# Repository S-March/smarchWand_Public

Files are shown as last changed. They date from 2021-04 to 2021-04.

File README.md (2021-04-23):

# smarchWand

smarchWand

I'm a huge dork. I love magic, have since I was a little kid. Now that I'm a grown up with some technical background knowledge, I made my own REAL magic wand!

For future projects and progress pictures, follow me on instagram @SamsonMarch

## Other Useful Links
To order circuit boards from the same place I did (with all the files pre-loaded and tech parameters filled out), you can [click this link](https://www.pcbway.com/project/shareproject/smarchWand.html)

To download the SDK for the DA14531, you can [click this link](https://support.dialog-semiconductor.com/system/files/restricted/SDK_6.0.14.1114.zip)

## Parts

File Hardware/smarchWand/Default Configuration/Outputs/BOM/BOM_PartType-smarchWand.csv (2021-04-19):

Quantity | Designator | Comment | Description
5 | R2, R3, R4, R5, R6 | 10k | 0402 Resistor
3 | C1, C3, C7 | 10uF | 0402 Capacitor
3 | C2, C5, C6 | 4.7uF | 0402 Capacitor
2 | R9, R10 | 5.1M | 0402 Resistor
1 | ANT1 | 2450AT18D0100E | 2450AT18D0100E 2.4GHz Chip RF Antenna 2.4GHz ~ 2.5GHz 1.5dBi Solder Surface Mount
1 | C4 | 100nF | 0402 Capacitor
1 | C8 | 1uF | 0402 Capacitor
1 | D1 | CUS10S30,H3F | CUS10S30,H3F Diode Schottky 30V 1A Surface Mount USC
1 | D2 | D5V0L1B2LP4-7B | D5V0L1B2LP4-7B 14V Clamp 6A (8/20µs) Ipp Tvs Diode Surface Mount X2-DFN1006-2
1 | L1 | CIGT201610EH2R2MNE | CIGT201610EH2R2MNE 2.2µH Unshielded Thin Film Inductor 2.5A 87mOhm Max 0806 (2016 Metric)
1 | M1 | C0720B001F | C0720B001F DC Motor Vibration, ERM 10000 RPM 3VDC
1 | P1 | TC2030-CTX-NL | TC2030-CTX-NL Tag Connect Cable
1 | Q1 | 2N7002K-7 | 2N7002K-7 MOSFET N-CH 60V 380MA SOT23-3
1 | Q2 | BSS84AKM,315 | BSS84AKM,315 MOSFET P-CH 50V SOT883
1 | Q3 | ECH8693R | Mosfet Array 2 N-Channel (Dual) Common Drain 24V 14A 1.4W Surface Mount SOT-28FL/ECH8
1 | R1 | 100 | 0805 Resistor
1 | R11 | 6.8k | 0402 Resistor
1 | R7 | 330 | 0402 Resistor
1 | R8 | 2.2K | 0402 Resistor
1 | U1 | DA14531 | DA14531 IC RF TxRx + MCU Bluetooth Bluetooth v5.1 2.4GHz 24-WFQFN, FC
1 | U2 | W25X20CLUXIG | W25X20CLUXIG FLASH Memory IC 2Mb (256K x 8) SPI 104MHz 8-USON (2x3)
1 | U3 | BQ29700DSER | Battery Battery Protection IC Lithium-Ion/Polymer 6-WSON (1.5x1.5)
1 | U4 | LM3671 | LM3671 IC REG BUCK 3.3V 0.6A SYNC 5USMD
1 | U5 | MCP73831T-2ACI/MC | MCP73831T-2ACI/MC Charger IC Lithium-Ion/Polymer
1 | U6 | LIS3DH | LIS3DH ACCEL 2-16G I2C/SPI 16LGA
1 | X1 | ECS-320-8-37B-CKY | ECS-320-8-37B-CKY CRYSTAL 32.0000MHZ 8PF SMD

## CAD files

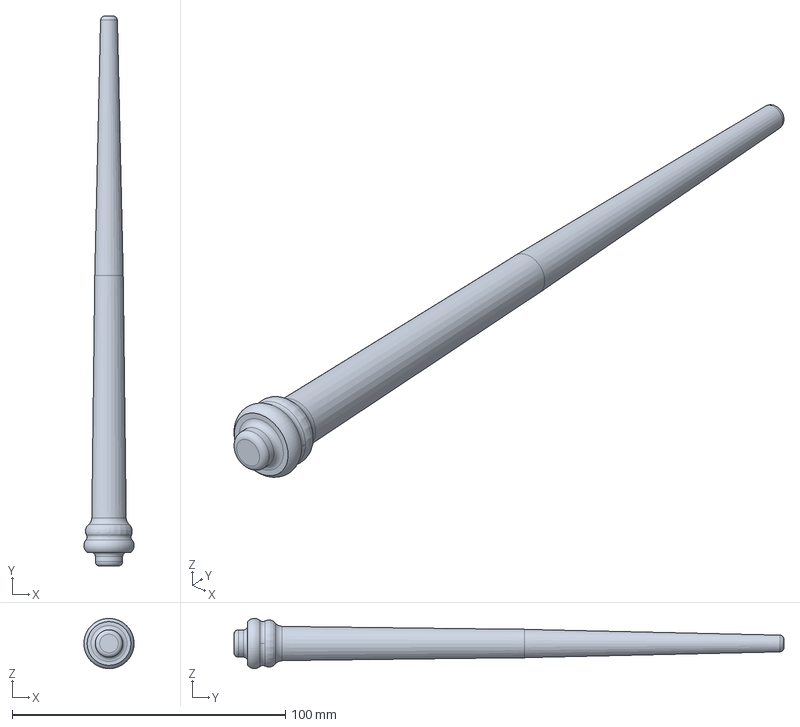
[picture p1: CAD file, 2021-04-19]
Housing/bodyShapeTopCap.step
18.4 x 201.4 x 18.4 mm

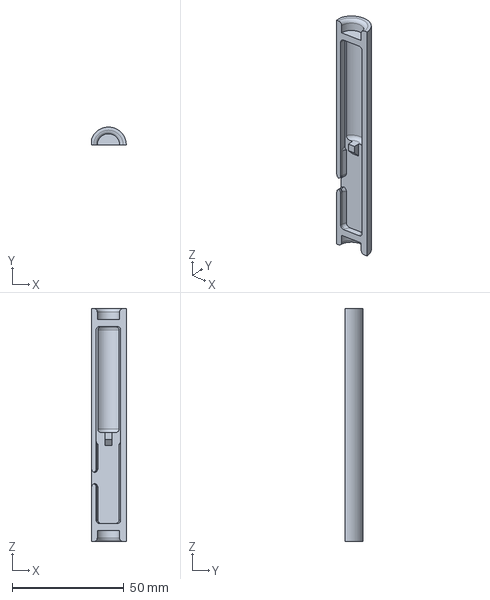
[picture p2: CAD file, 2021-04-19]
Housing/bodyShapeCenterTop.step
15.5 x 8.00 x 104.1 mm

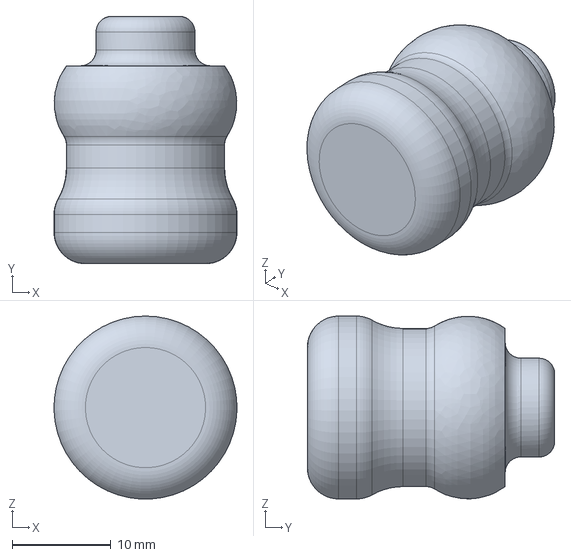
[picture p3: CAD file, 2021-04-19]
Housing/bodyShapeBottomCap.step
18.5 x 25.0 x 18.5 mm

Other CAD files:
Housing/bodyShapeCenterBottom.step

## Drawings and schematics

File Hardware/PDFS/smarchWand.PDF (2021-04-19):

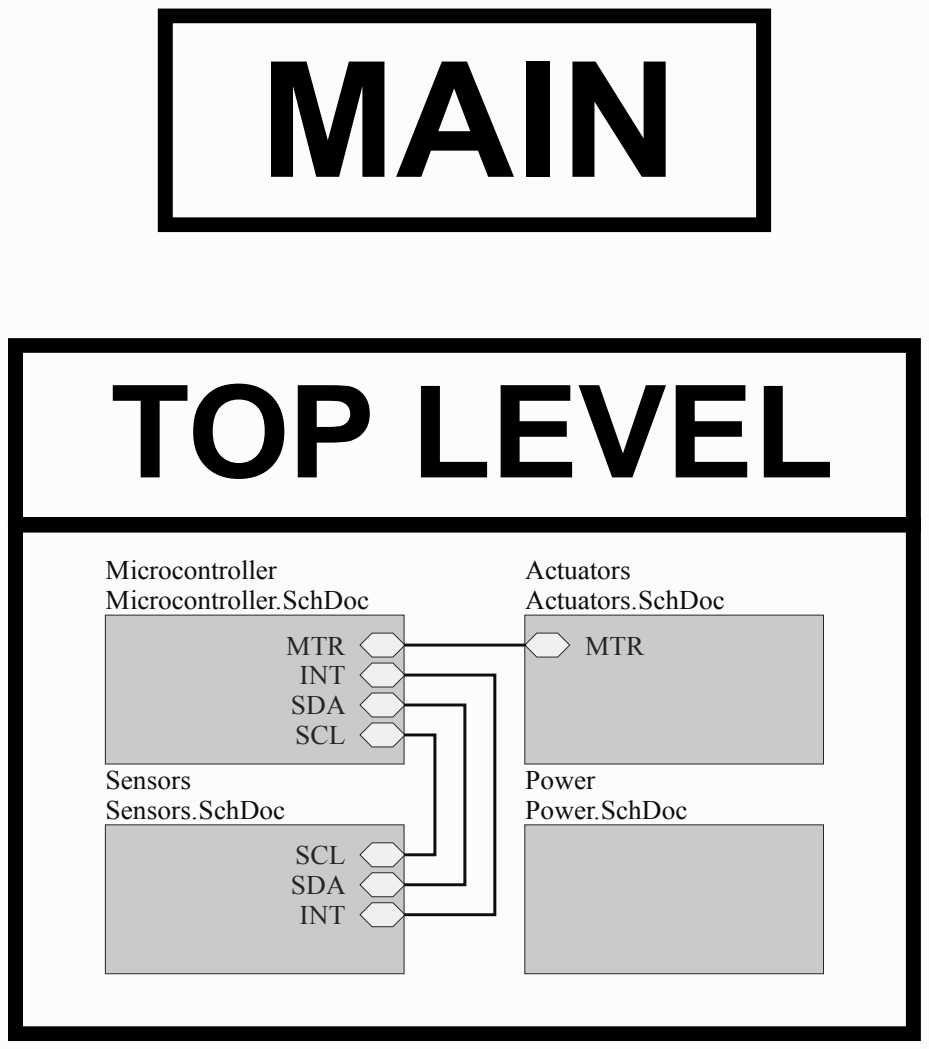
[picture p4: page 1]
TOP LEVEL

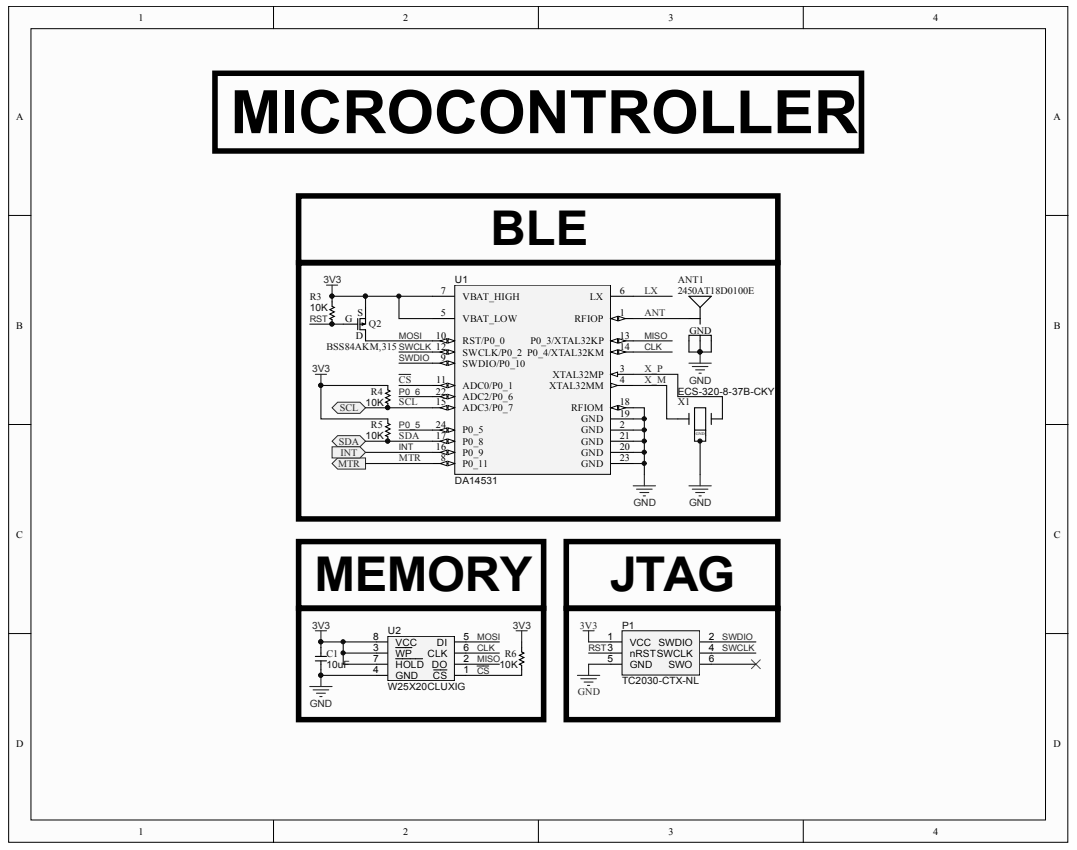
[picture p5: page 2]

R4 10K SCL | P0_6 | ADC3/P0_7 15 ADC2/P0_6 22 ADC0/P0_1 11

X_M GND

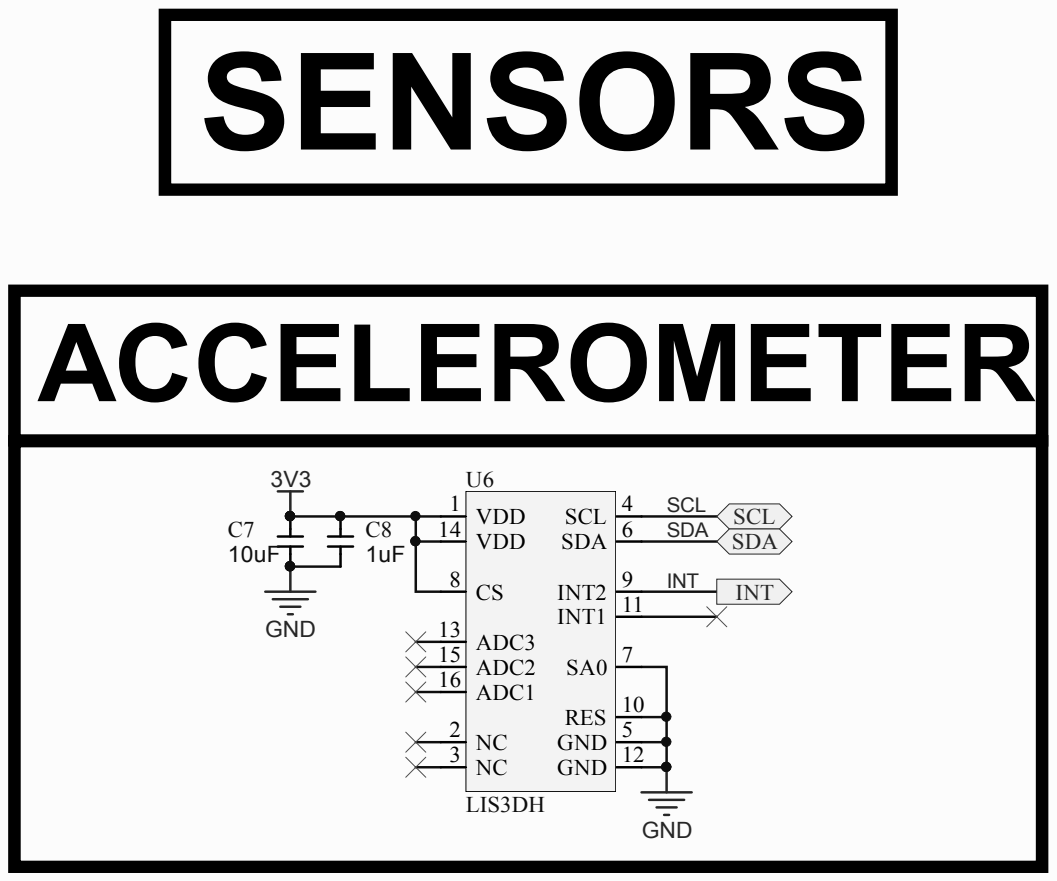
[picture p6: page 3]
VDD 1; INT2; ADC3 13; VDD 14; ADC2 15 ADC1 16

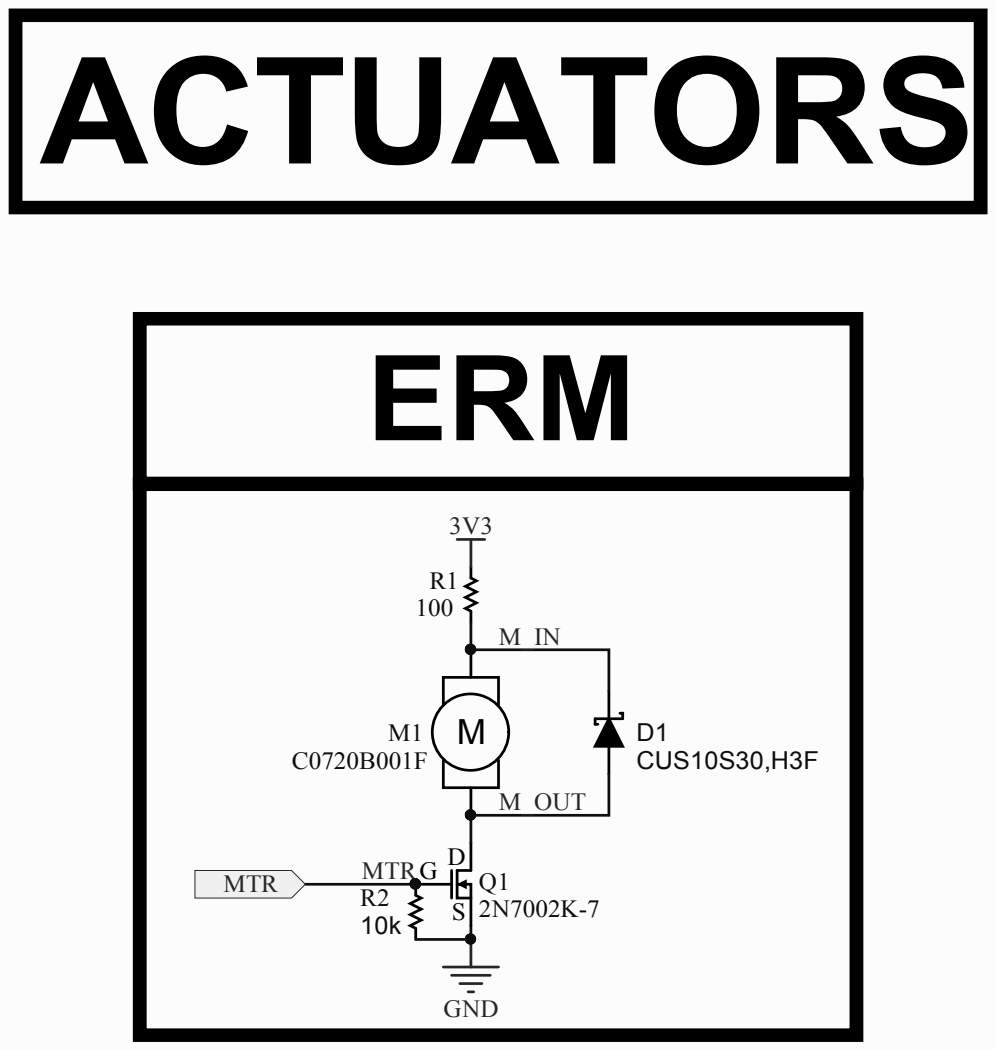
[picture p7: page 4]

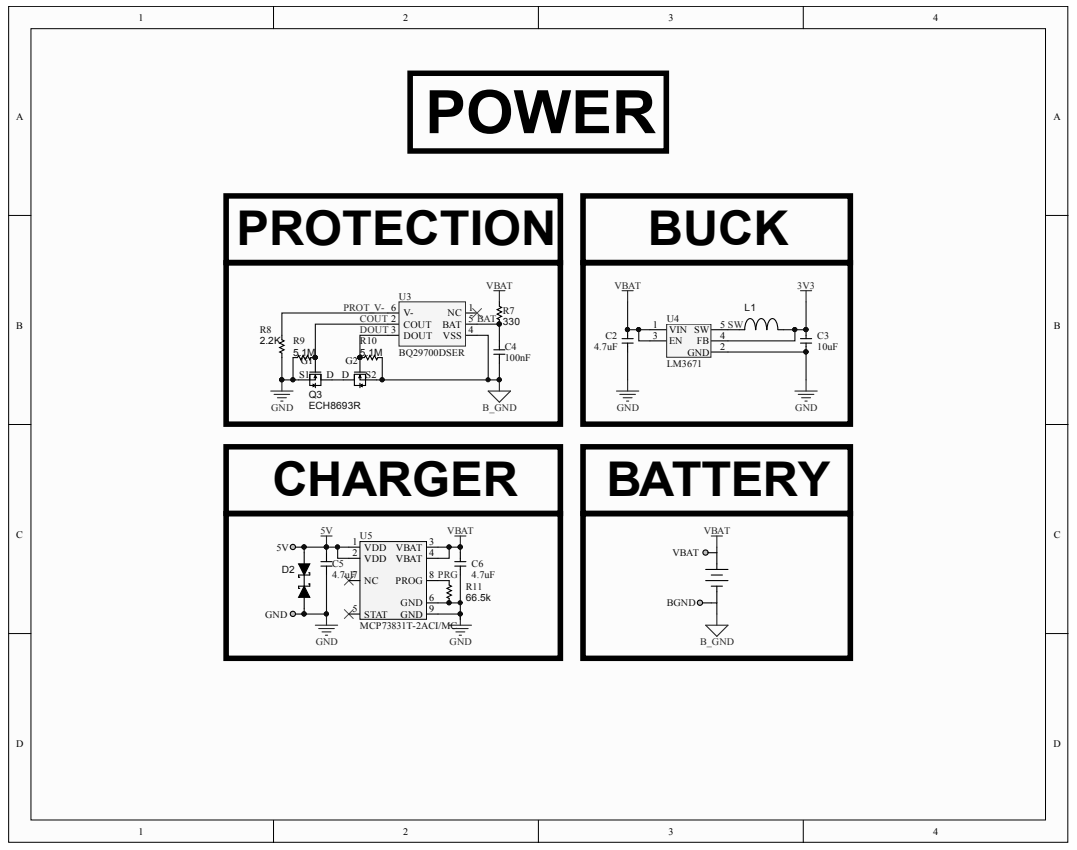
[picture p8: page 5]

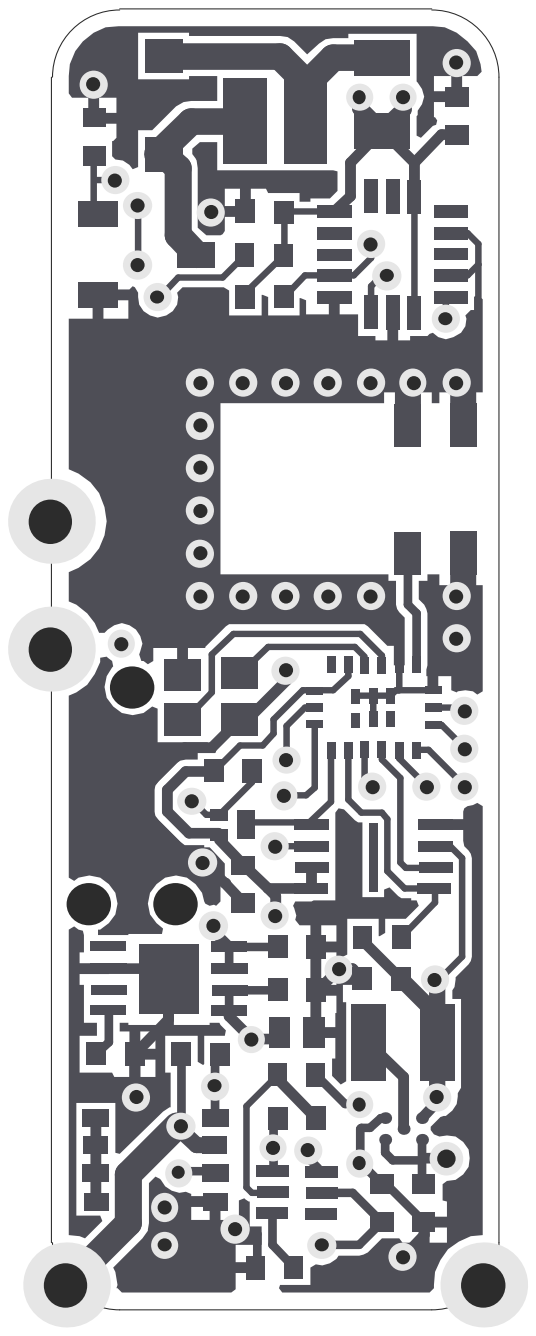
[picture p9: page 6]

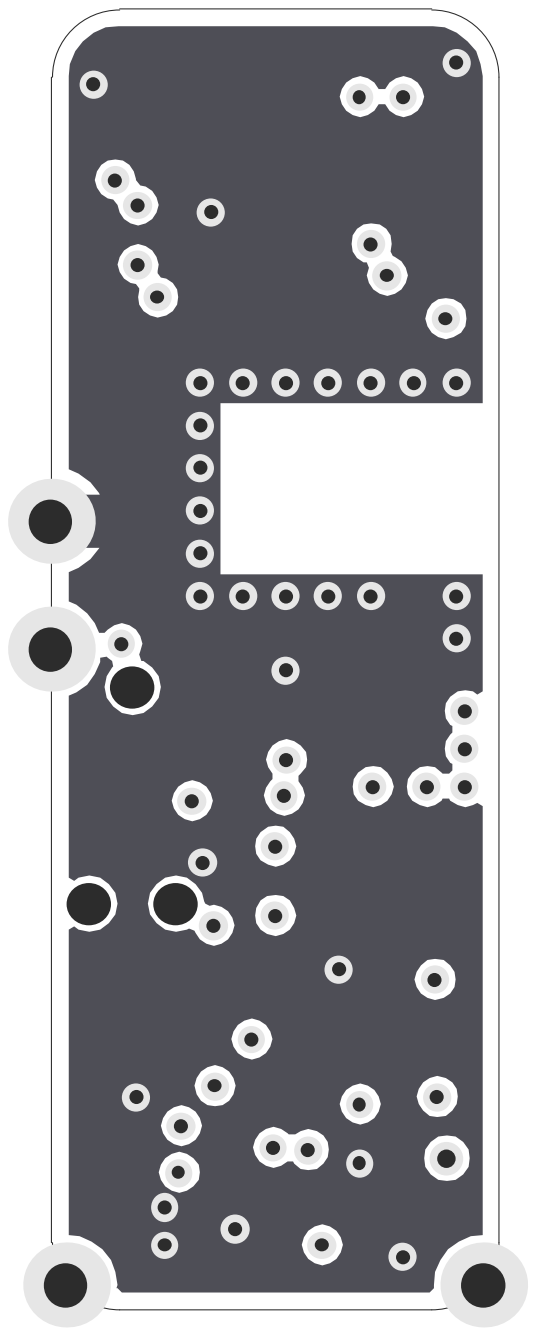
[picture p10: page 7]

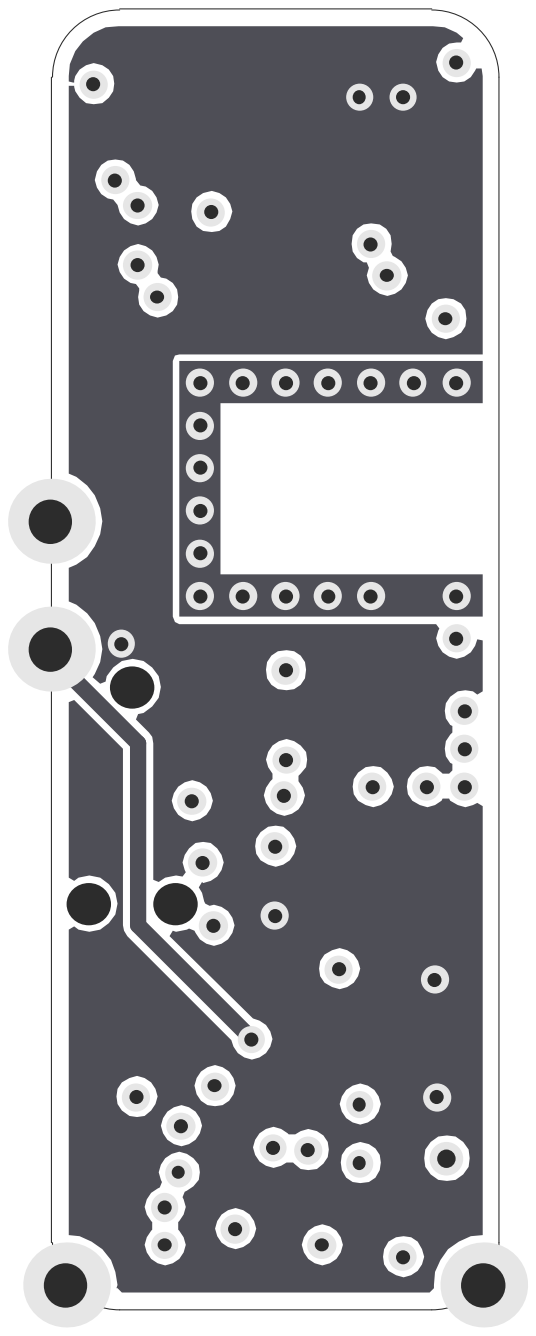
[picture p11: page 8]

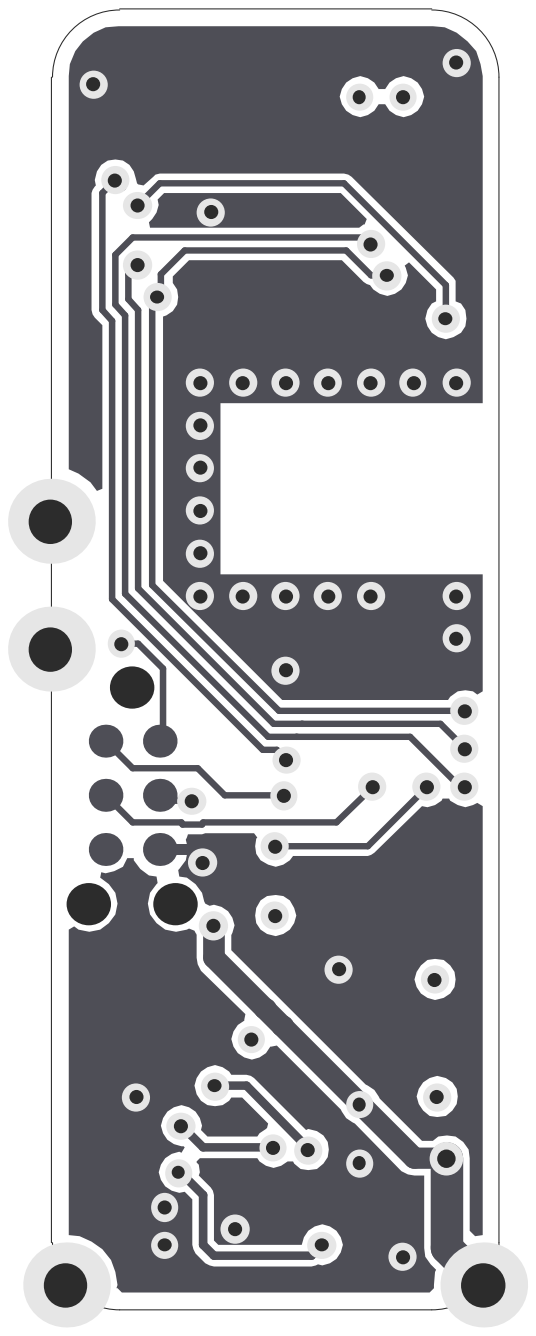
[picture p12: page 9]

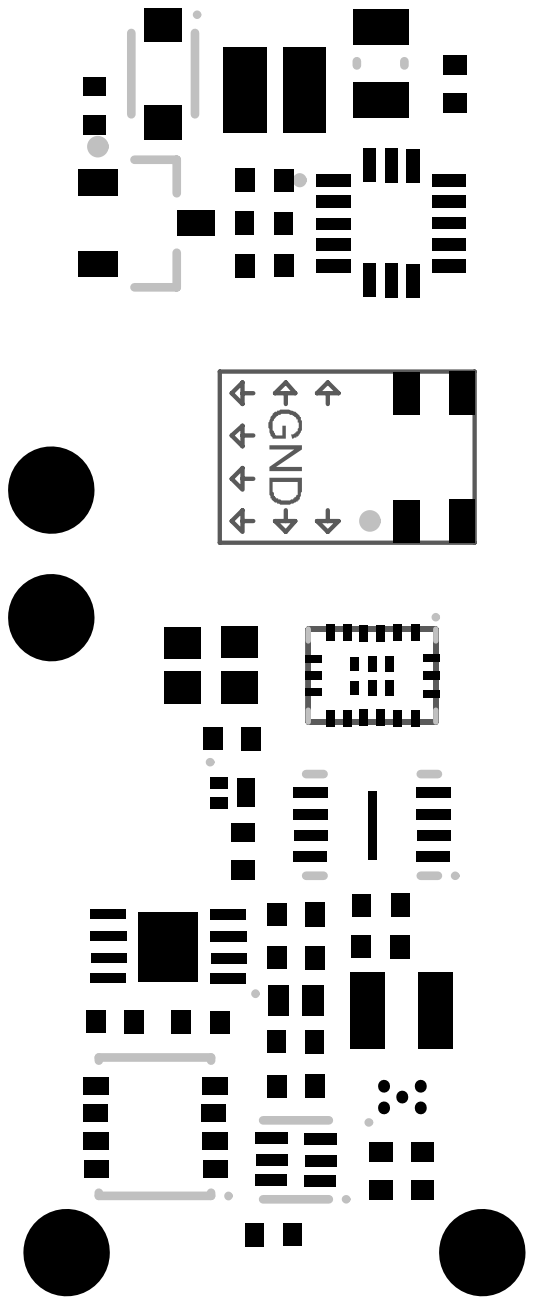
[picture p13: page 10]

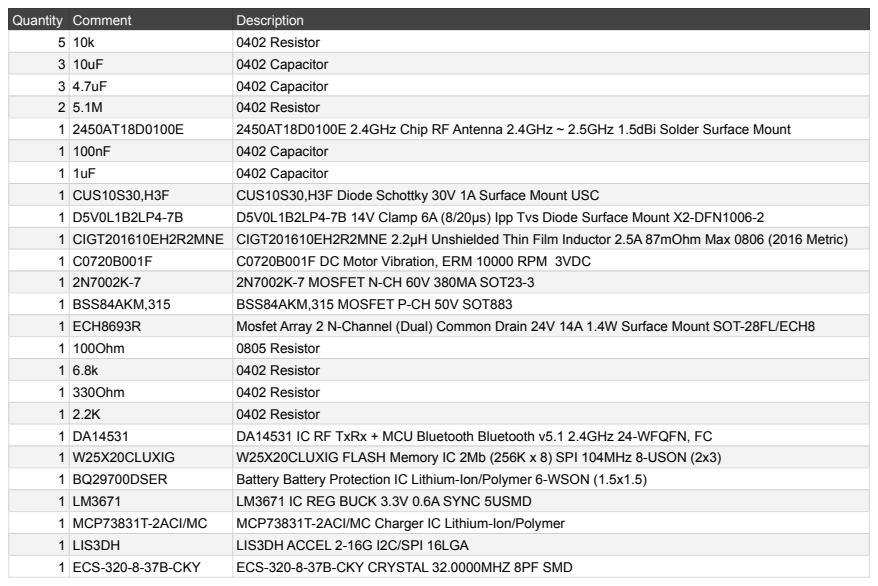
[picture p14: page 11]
Quantity Comment; Description; 0402 Resistor; 0402 Capacitor; 2450AT18D0100E 2.4GHz Chip RF Antenna 2.4GHz ~ 2.5GHz 1.5dBi Solder Surface Mount; 1 CUS10S30,H3F; CUS10S30,H3F Diode Schottky 30V 1A Surface Mount USC; D5V0L1B2LP4-7B 14V Clamp 6A (8/20µs) Ipp Tvs Diode Surface Mount X2-DFN1006-2; C0720B001F DC Motor Vibration, ERM 10000 RPM 3VDC; 2N7002K-7 MOSFET N-CH 60V 380MA SOT23-3; 1 BSS84AKM,315; BSS84AKM,315 MOSFET P-CH 50V SOT883; 1 ECH8693R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

1 CIGT201610EH2R2MNE CIGT201610EH2R2MNE 2.2µH Unshielded Thin Film Inductor 2.5A 87mOhm Max 0806 (2016 Metric)

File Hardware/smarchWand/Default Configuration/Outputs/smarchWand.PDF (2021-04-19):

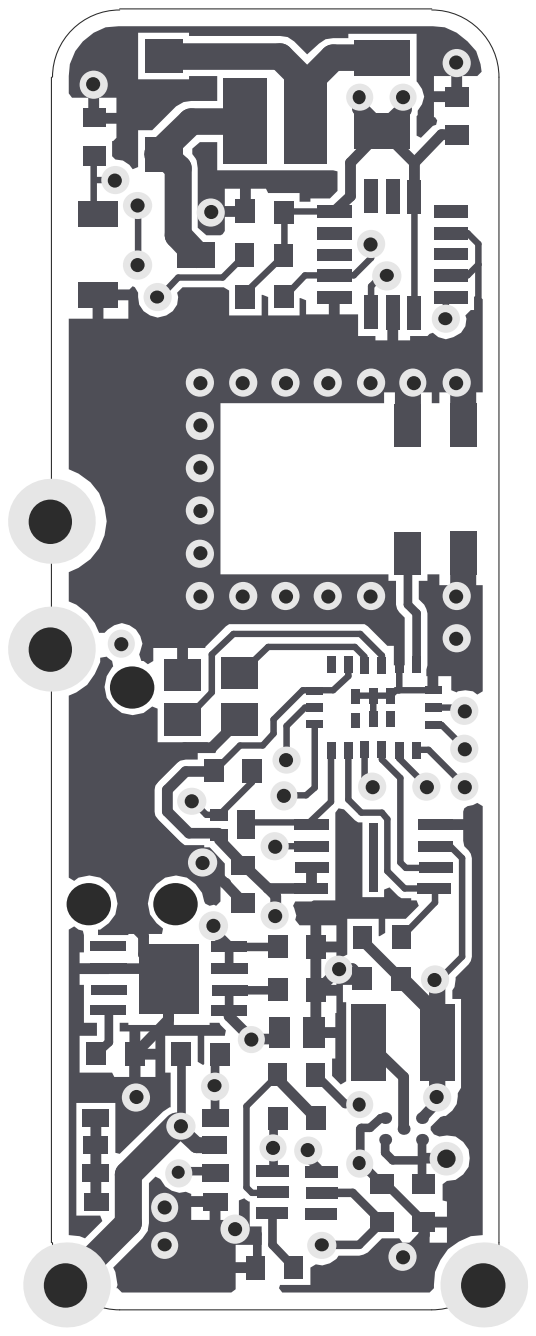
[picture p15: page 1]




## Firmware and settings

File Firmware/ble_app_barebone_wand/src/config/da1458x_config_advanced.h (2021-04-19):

/**
 ****************************************************************************************
 *
 * @file da1458x_config_advanced.h
 *
 * @brief Advanced compile configuration file.
 *
 * Copyright (C) 2014-2020 Dialog Semiconductor.
 * This computer program includes Confidential, Proprietary Information
 * of Dialog Semiconductor. All Rights Reserved.
 *
 ****************************************************************************************
 */

#ifndef _DA1458X_CONFIG_ADVANCED_H_
#define _DA1458X_CONFIG_ADVANCED_H_

#include "da1458x_stack_config.h"

#if !defined (__DA14531__)

/****************************************************************************************************************/
/* Low Power clock selection.                                                                                   */
/*      -LP_CLK_XTAL32      External XTAL32K oscillator                                                         */
/*      -LP_CLK_RCX20       Internal RCX clock                                                                  */
/*      -LP_CLK_FROM_OTP    Use the selection in the corresponding field of OTP Header                          */
/*                                                                                                              */
/* NOTE: Disable CFG_XTAL16M_ADAPTIVE_SETTLING flag when RCX is chosen as the LP clock either from the OTP      */
/*       header or from the SDK.                                                                                */
/****************************************************************************************************************/
#define CFG_LP_CLK              LP_CLK_XTAL32

/****************************************************************************************************************/
/* If defined the application uses a hardcoded value for XTAL16M trimming. Should be disabled for devices       */
/* where XTAL16M is calibrated and trim value is stored in OTP.                                                 */
/* Important note. The hardcoded value is the average value of the trimming values giving the optimal results   */
/* for DA14585 DK devices. May not be applicable in other designs                                               */
/****************************************************************************************************************/
#define CFG_USE_DEFAULT_XTAL16M_TRIM_VALUE_IF_NOT_CALIBRATED

/****************************************************************************************************************/
/* Periodic wakeup period to poll GTL iface. Time in msec.                                                      */
/****************************************************************************************************************/
#define CFG_MAX_SLEEP_DURATION_PERIODIC_WAKEUP_MS                  500  // 0.5s

/****************************************************************************************************************/
/* Periodic wakeup period if GTL iface is not enabled. Time in msec.                                            */
/****************************************************************************************************************/
#define CFG_MAX_SLEEP_DURATION_EXTERNAL_WAKEUP_MS              600000  // 600s

/****************************************************************************************************************/
/* Wakeup from external processor running host application.                                                     */
/****************************************************************************************************************/
#undef CFG_EXTERNAL_WAKEUP

/****************************************************************************************************************/
/* Wakeup external processor when a message is sent to GTL                                                      */
/****************************************************************************************************************/
#undef CFG_WAKEUP_EXT_PROCESSOR
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

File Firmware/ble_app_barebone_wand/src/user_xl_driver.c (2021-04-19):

/*
 * INCLUDE FILES
 ****************************************************************************************
 */

#include <stdint.h>
#include <stdbool.h>
#include <string.h>
#include "compiler.h"
#include "ll.h"
#include "user_xl_driver.h"
#include "i2c.h"
#include "stdlib.h"


volatile int8_t previousData[3];

 /**
 ****************************************************************************************
 * @brief Initialize I2C Accelerometer
 ****************************************************************************************
 */
void i2c_XL_initialize(void)
	{
	uint8_t registerToSend[2];
	uint8_t xlData[2];
	i2c_abort_t abrt_code;
	//Disable controller to change slave address 
	i2c_set_controller_status(I2C_CONTROLLER_DISABLE);
	while ((i2c_get_controller_status() != I2C_CONTROLLER_DISABLE));
	i2c_set_target_address(XL_ADDRESS);
	i2c_set_controller_status(I2C_CONTROLLER_ENABLE);
	while ((i2c_get_controller_status() != I2C_CONTROLLER_ENABLE));
		
	registerToSend[0] = XL_CONTROL_REG_1;
	registerToSend[1] = 0x57;
	i2c_master_transmit_buffer_sync(registerToSend,sizeof(registerToSend),&abrt_code,I2C_F_ADD_STOP);
	
	//Set to off
	registerToSend[0] = XL_INT1_CFG;
	registerToSend[1] = 0x00;
	i2c_master_transmit_buffer_sync(registerToSend,sizeof(registerToSend),&abrt_code,I2C_F_ADD_STOP);
		
	i2c_master_transmit_buffer_sync(registerToSend,sizeof(registerToSend),&abrt_code,I2C_F_NONE);
	i2c_master_receive_buffer_sync(&xlData[0], sizeof(&xlData[0]), &abrt_code, I2C_F_ADD_STOP);
	previousData[0] = 0;
	previousData[1] = 0;
	previousData[2] = 0;
 }
	
 /**
 ****************************************************************************************
 * @brief Read X-axis I2C Accelerometer
 ****************************************************************************************
 */
uint16_t i2c_XL_Read_X(void)
	{
	uint8_t registerToSend[2];
	uint8_t xlData[2];

	i2c_abort_t abrt_code;
	volatile uint16_t returnValue = 0;
	//Disable controller to change slave address 
	i2c_set_controller_status(I2C_CONTROLLER_DISABLE);
	while ((i2c_get_controller_status() != I2C_CONTROLLER_DISABLE));
	i2c_set_target_address(XL_ADDRESS);
	i2c_set_controller_status(I2C_CONTROLLER_ENABLE);
	while ((i2c_get_controller_status() != I2C_CONTROLLER_ENABLE));
		
	registerToSend[0] = XL_OUT_X_L;
	registerToSend[1] = XL_OUT_X_H;
	
	i2c_master_transmit_buffer_sync(&registerToSend[0],sizeof(&registerToSend[0]),&abrt_code,I2C_F_NONE);
	i2c_master_receive_buffer_sync(&xlData[0], sizeof(&xlData[0]), &abrt_code, I2C_F_ADD_STOP);
	returnValue = xlData[0];
		
	i2c_master_transmit_buffer_sync(&registerToSend[1],sizeof(&registerToSend[1]),&abrt_code,I2C_F_NONE);
	i2c_master_receive_buffer_sync(&xlData[1], sizeof(&xlData[1]), &abrt_code, I2C_F_ADD_STOP);
	returnValue |= xlData[1] << 8;
		
	return returnValue;
 }
	
 /**
 ****************************************************************************************
 * @brief Read Y-axis I2C Accelerometer
 ****************************************************************************************
 */
uint16_t i2c_XL_Read_Y(void)
	{
	uint8_t registerToSend[2];
	uint8_t xlData[2];

	i2c_abort_t abrt_code;
	volatile uint16_t returnValue = 0;
	//Disable controller to change slave address 
	i2c_set_controller_status(I2C_CONTROLLER_DISABLE);
	while ((i2c_get_controller_status() != I2C_CONTROLLER_DISABLE));
	i2c_set_target_address(XL_ADDRESS);
	i2c_set_controller_status(I2C_CONTROLLER_ENABLE);
	while ((i2c_get_controller_status() != I2C_CONTROLLER_ENABLE));
		
	registerToSend[0] = XL_OUT_Y_L;
	registerToSend[1] = XL_OUT_Y_H;
		
	i2c_master_transmit_buffer_sync(&registerToSend[0],sizeof(&registerToSend[0]),&abrt_code,I2C_F_NONE);
	i2c_master_receive_buffer_sync(&xlData[0], sizeof(&xlData[0]), &abrt_code, I2C_F_ADD_STOP);
	returnValue = xlData[0];
		
	i2c_master_transmit_buffer_sync(&registerToSend[1],sizeof(&registerToSend[1]),&abrt_code,I2C_F_NONE);
	i2c_master_receive_buffer_sync(&xlData[1], sizeof(&xlData[1]), &abrt_code, I2C_F_ADD_STOP);
	returnValue |= xlData[1] << 8;
		
	return returnValue;
 }
	
 /**
 ****************************************************************************************
 * @brief Read Z-axis I2C Accelerometer
 ****************************************************************************************
 */
uint16_t i2c_XL_Read_Z(void)
	{
	uint8_t registerToSend[2];
	uint8_t xlData[2];

	i2c_abort_t abrt_code;
	volatile uint16_t returnValue = 0;
	//Disable controller to change slave address 
	i2c_set_controller_status(I2C_CONTROLLER_DISABLE);
	while ((i2c_get_controller_status() != I2C_CONTROLLER_DISABLE));
	i2c_set_target_address(XL_ADDRESS);
	i2c_set_controller_status(I2C_CONTROLLER_ENABLE);
	while ((i2c_get_controller_status() != I2C_CONTROLLER_ENABLE));
		
	registerToSend[0] = XL_OUT_Z_L;
	registerToSend[1] = XL_OUT_Z_H;
		
	i2c_master_transmit_buffer_sync(&registerToSend[0],sizeof(&registerToSend[0]),&abrt_code,I2C_F_NONE);
	i2c_master_receive_buffer_sync(&xlData[0], sizeof(&xlData[0]), &abrt_code, I2C_F_ADD_STOP);
	returnValue = xlData[0];
		
	i2c_master_transmit_buffer_sync(&registerToSend[1],sizeof(&registerToSend[1]),&abrt_code,I2C_F_NONE);
	i2c_master_receive_buffer_sync(&xlData[1], sizeof(&xlData[1]), &abrt_code, I2C_F_ADD_STOP);
	returnValue |= xlData[1] << 8;
		
	return returnValue;
 }
	
 /**
 ****************************************************************************************
 * @brief Read all-axis I2C Accelerometer
 ****************************************************************************************
 */
void i2c_XL_Read_ALL(void)
{
	volatile int16_t xlOutData[3] = {0,0,0};

	xlOutData[0] = i2c_XL_Read_X();
	xlOutData[1] = i2c_XL_Read_Y();
	xlOutData[2] = i2c_XL_Read_Z();
}

 /**
 ****************************************************************************************
 * @brief Get largest vector direction of XL
 * @input 4 cell array (x,y,z,largest delta)
 ****************************************************************************************
 */
void i2c_XL_Vector_Delta(int8_t *vectorData)
{	
	volatile int8_t xlOutData[3] = {0,0,0};
	volatile int8_t minMaxValue = 0;
	volatile int8_t largestDelta = 0;

	xlOutData[0] = (i2c_XL_Read_X()>>8);
	xlOutData[1] = (i2c_XL_Read_Y()>>8);
	xlOutData[2] = (i2c_XL_Read_Z()>>8);
	
	for(int i=0;i<3;i++)
	{		
		vectorData[i] = xlOutData[i]-previousData[i];	
		previousData[i] = xlOutData[i];
		if(abs(vectorData[i])>minMaxValue)
		{
			minMaxValue = abs(vectorData[i]);
			largestDelta = i;
		}
	}
	vectorData[3] = largestDelta;
}
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
